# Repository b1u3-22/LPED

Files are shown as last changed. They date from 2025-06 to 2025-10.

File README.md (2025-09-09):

# LPED

Highly customizable Low-power Electronic Playing Dice

> This project started as a bachelors thesis, the original repository can be found [here](https://git.fit.vutbr.cz/xsedla2e/BP-LPED)

## Features

* Separate charging station for charging the dice via pogo-pins
* Changing the dice shape with custom sleeves 
* The dice can be configured to support any shape with up to 60 sides
* Up to 10 profiles can be saved onboard 

### Hardware 

* The dice uses a nRF52833 microcontroller with FXLS8974CF accelerometer
* Instead of battery it uses hybrid super-capacitor with 20 F capacity that provides up to 8 hours of game time with charging time of 15 minutes
* RGB LED on-board the dice
* The charger has separate battery providing up to two full dice charges
* The 3D models of the charging dock have been optimized for 3D printing and they do not require any supports
	* However, one heat inserts and 4 magnets (6x6x2mm) are necessary for the assembly

### Firmware 

* The dice transmits the landed numbers via BLE broadcast advertisement
	* To ensure they get to the client application, they are sent multiple times with unique identifier
* For configuration it is necessary to connect to the dice
	* It provides all the necessary parameters via characteristics in custom GATT service
* It saves the whole configuration in the FLASH memory of the dice, making it independent on the used client application
* Each side can have its own physical position on the dice and its own number, making it possible to create dice with custom non-standard shapes

## Project structure 
* `/hardware` - schematics, 3D models and PCB design files for dice, charger and programming adapter
	* The schematics and PCB designs were made in KiCad 
	* The printable models were made in FreeCAD 
* `/firmware` - Zephyr firmware running on the dice

## Versioning info 
* Repository uses `major.minor` format
	* `major` is incremented with each major hardware revision or significant firmware update that causes the implementation to be incompatible with previous version
	* `minor` is used for firmware fixes and patches that don't affect backwards compatibility
	* Branch names are created based on major revisions 
* PCBs have their own version code on them that follows standard `major.minor` format
	* `major` is used for drastic changes to the boards, such as MCU swap or change of pinout
	* `minor` is used for hardware fixes and patches

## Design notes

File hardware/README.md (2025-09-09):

# Hardware designs 
* Schematic, PCB design files and used 3D models used in the design for the die, charging dock and programming adapter
* The `complete_bom.csv` contains BOM with components selected from Mouser

## Structure
1. `lped`
    * Design files for the die
2. `lped_dock`
    * Design files for for the modular charging station and single dice charging station
3. `lped_prog`
    * Design files for the programming adapter
2. `3d_models`
    * 3D models used in PCB design files in all three boards

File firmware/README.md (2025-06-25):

# Firmware for LPED
* Zephyr firmware running on the die
* The `src/lib` contains helper function and structure definitions for controlling the die, dock and determining the current number on top
* A FXLS8974 driver is required to be placed in `modules` and it is available at: https://git.fit.vutbr.cz/xsedla2e/BP-FXLS89xx-Driver

## `src/lib` structure
1. `bma400`
    * Older driver for BMA400 accelerometer
    * Not currently used
2. `bt`
    * Contains structure for Bluetooth aspects of the die and functions to send messages and change the Bluetooth states
    * `bt_dice.h` also contains definitions for message types
3. `dock`
    * Contains structure and functions for controlling the charging dock - LED and button handling
4. `phy`
    * Contains structure for physical aspects of the die - controlling the LED and getting the capacitor state
5. `side`
    * Contains array with all supported sides and their vector values and function to determine the current side
6. `led_defs.h`
    * LED speed definitions

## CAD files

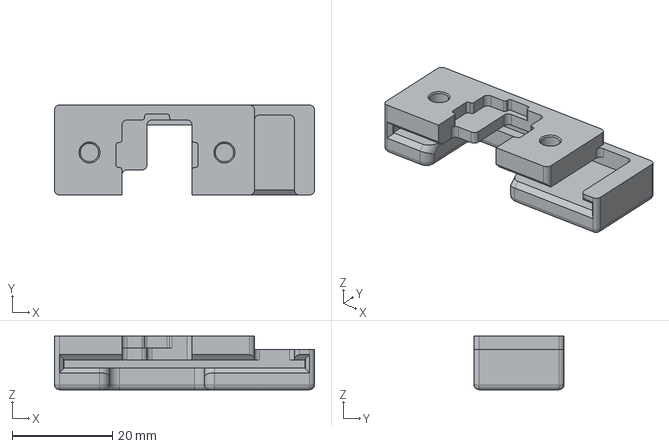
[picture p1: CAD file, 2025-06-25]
hardware/lped_prog/3d_models/step/main_body.step
52.0 x 18.0 x 10.7 mm

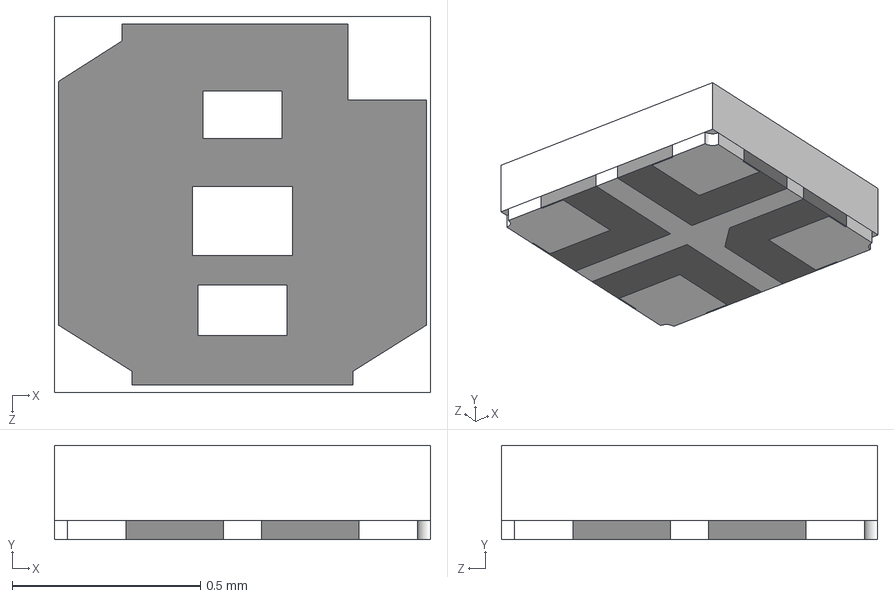
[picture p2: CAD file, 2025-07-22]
hardware/3d_models/LTRBR37G-4R4S-0125-0.stp
1.00 x 0.25 x 1.00 mm

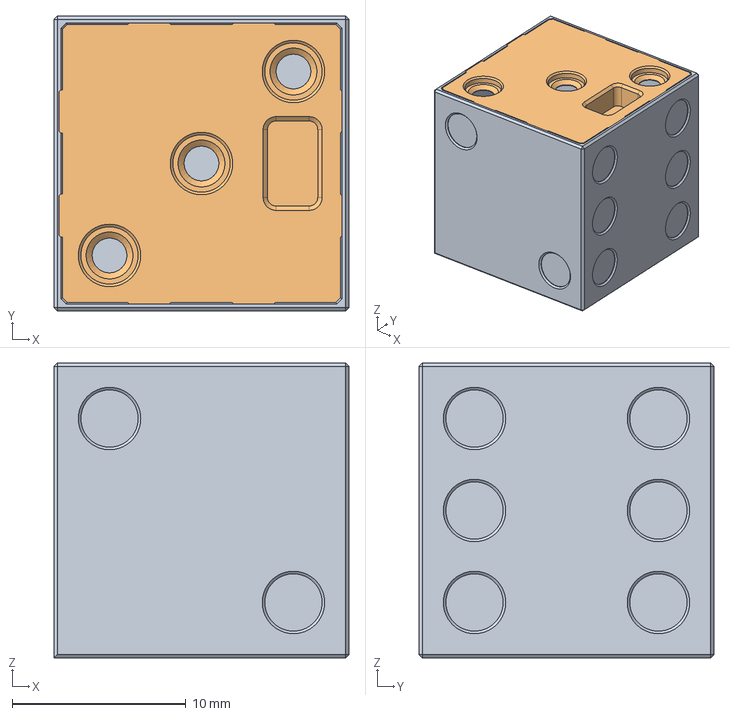
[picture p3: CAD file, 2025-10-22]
hardware/lped/3d_models/die_6.FCStd
17.0 x 17.0 x 17.0 mm
cap

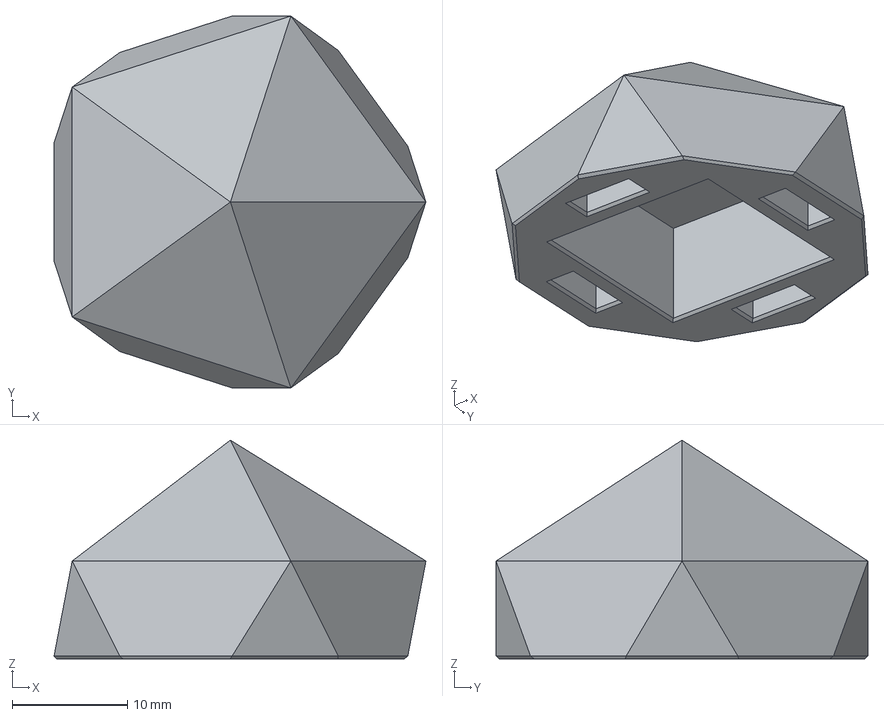
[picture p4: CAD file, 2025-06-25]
hardware/lped/3d_models/step/dice_20_top.step
32.3 x 32.3 x 19.0 mm

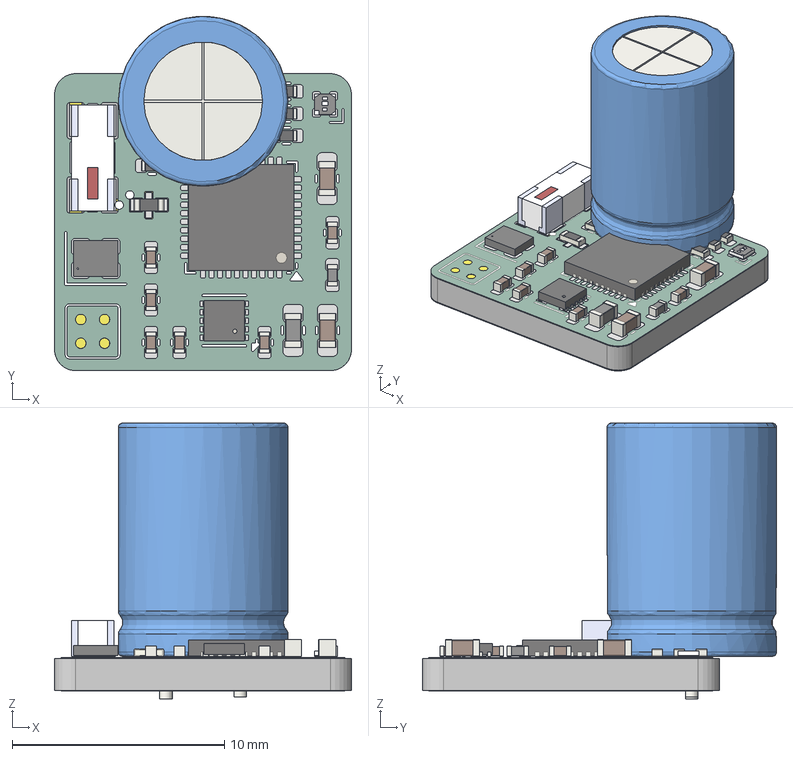
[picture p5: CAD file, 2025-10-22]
hardware/lped/schematics/3d_models/lped_pcb.step
14.0 x 16.7 x 13.0 mm
fxls8974cf
C_0603_1608Metric x 2
C_Radial_D8.0mm_H11.5mm_P3.50mm
LTRBR37G-4R4S-0125-0
R_0402_1005Metric x 5
C_0402_1005Metric x 6
QFN-40-1EP_5x5mm_P0.4mm_EP3.6x3.6mm
L_0402_1005Metric
L_0603_1608Metric
FA-128_EPS
2450AT42E010BE
lped_copper
lped_pad
lped_via
lped_silkscreen x 2
lped_soldermask x 2
lped_PCB

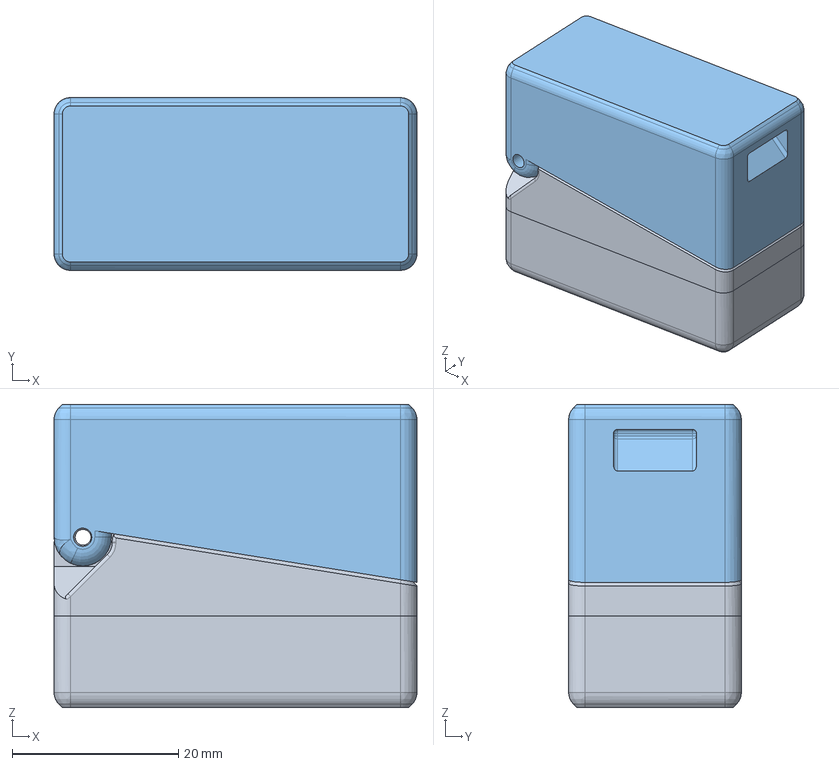
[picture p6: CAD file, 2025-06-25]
hardware/lped_dock/single_dock/3d_models/single_charger.FCStd
43.7 x 20.8 x 36.5 mm
bottom
R_0402_1005Metric
USB_C_Receptacle_GCT_USB4105-xx-A_16P_TopMnt_Horizontal
USB_C_Receptacle_GCT_USB4105-xx-A_16P_TopMnt_Horizontal001
USB_C_Receptacle_GCT_USB4105-xx-A_16P_TopMnt_Horizontal002
USB_C_Receptacle_GCT_USB4105-xx-A_16P_TopMnt_Horizontal003
USB_C_Receptacle_GCT_USB4105-xx-A_16P_TopMnt_Horizontal004
USB_C_Receptacle_GCT_USB4105-xx-A_16P_TopMnt_Horizontal005
USB_C_Receptacle_GCT_USB4105-xx-A_16P_TopMnt_Horizontal006
USB_C_Receptacle_GCT_USB4105-xx-A_16P_TopMnt_Horizontal007
USB_C_Receptacle_GCT_USB4105-xx-A_16P_TopMnt_Horizontal008
USB_C_Receptacle_GCT_USB4105-xx-A_16P_TopMnt_Horizontal009
USB_C_Receptacle_GCT_USB4105-xx-A_16P_TopMnt_Horizontal010
USB_C_Receptacle_GCT_USB4105-xx-A_16P_TopMnt_Horizontal011
USB_C_Receptacle_GCT_USB4105-xx-A_16P_TopMnt_Horizontal012
USB_C_Receptacle_GCT_USB4105-xx-A_16P_TopMnt_Horizontal013
USB_C_Receptacle_GCT_USB4105-xx-A_16P_TopMnt_Horizontal014
USB_C_Receptacle_GCT_USB4105-xx-A_16P_TopMnt_Horizontal015
USB_C_Receptacle_GCT_USB4105-xx-A_16P_TopMnt_Horizontal016
USB_C_Receptacle_GCT_USB4105-xx-A_16P_TopMnt_Horizontal017
USB_C_Receptacle_GCT_USB4105-xx-A_16P_TopMnt_Horizontal018
USB_C_Receptacle_GCT_USB4105-xx-A_16P_TopMnt_Horizontal019
USB_C_Receptacle_GCT_USB4105-xx-A_16P_TopMnt_Horizontal020
USB_C_Receptacle_GCT_USB4105-xx-A_16P_TopMnt_Horizontal021
USB_C_Receptacle_GCT_USB4105-xx-A_16P_TopMnt_Horizontal022
USB_C_Receptacle_GCT_USB4105-xx-A_16P_TopMnt_Horizontal023
USB_C_Receptacle_GCT_USB4105-xx-A_16P_TopMnt_Horizontal024
USB_C_Receptacle_GCT_USB4105-xx-A_16P_TopMnt_Horizontal025
USB_C_Receptacle_GCT_USB4105-xx-A_16P_TopMnt_Horizontal026
USB_C_Receptacle_GCT_USB4105-xx-A_16P_TopMnt_Horizontal027
USB_C_Receptacle_GCT_USB4105-xx-A_16P_TopMnt_Horizontal028
USB_C_Receptacle_GCT_USB4105-xx-A_16P_TopMnt_Horizontal029
USB_C_Receptacle_GCT_USB4105-xx-A_16P_TopMnt_Horizontal030
USB_C_Receptacle_GCT_USB4105-xx-A_16P_TopMnt_Horizontal031
USB_C_Receptacle_GCT_USB4105-xx-A_16P_TopMnt_Horizontal032
USB_C_Receptacle_GCT_USB4105-xx-A_16P_TopMnt_Horizontal033
USB_C_Receptacle_GCT_USB4105-xx-A_16P_TopMnt_Horizontal034
USB_C_Receptacle_GCT_USB4105-xx-A_16P_TopMnt_Horizontal035
R_0402_1005Metric001
L_0805_2012Metric
pogo_pin-7mm
C_0603_1608Metric
APTD2012LSURCK
APTD2012LSURCK001
APTD2012LSURCK002
APTD2012LSURCK003
APTD2012LSURCK004
APTD2012LSURCK005
C_0603_1608Metric001
R_0402_1005Metric002
R_0402_1005Metric003
pogo_pin-7mm001
R_0402_1005Metric004
R_2512_6332Metric
pogo_pin-7mm002
SW_SPST_PTS645
pogo_pin-7mm003
pogo_pin-7mm004
R_0402_1005Metric005
R_0402_1005Metric006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

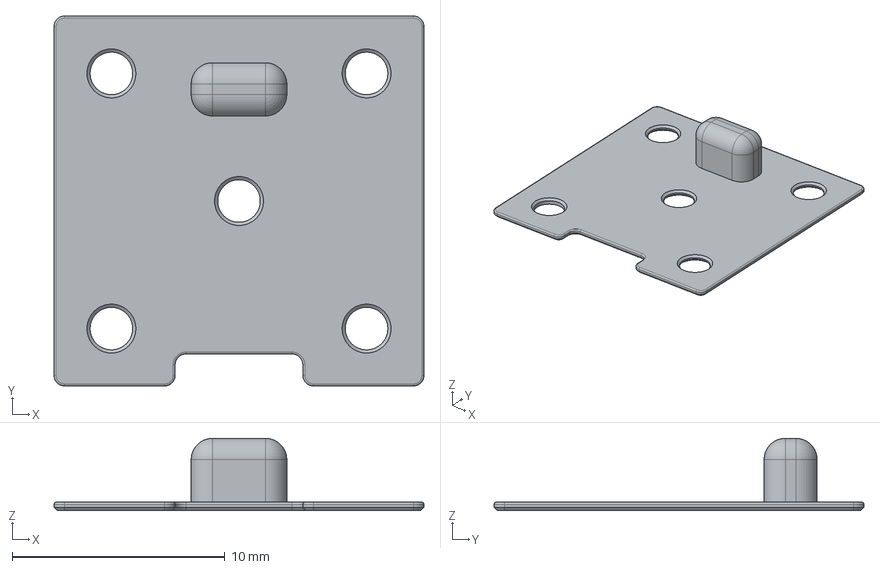
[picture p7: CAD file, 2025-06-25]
hardware/lped_dock/single_dock/3d_models/step/bay_insert.step
17.4 x 17.4 x 3.40 mm

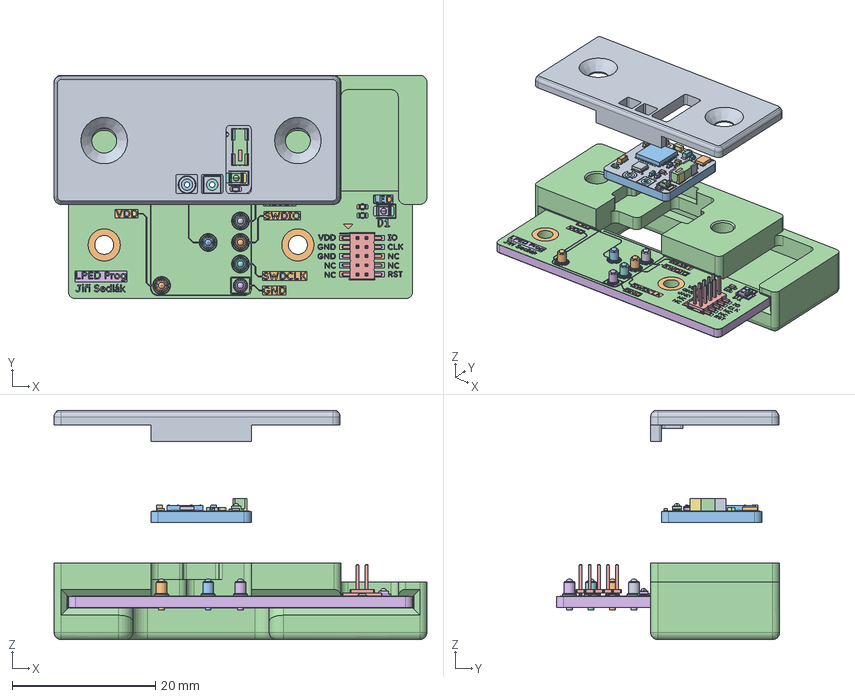
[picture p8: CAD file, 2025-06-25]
hardware/lped_prog/3d_models/hard_clamp_top.FCStd
52.0 x 31.2 x 32.0 mm
clamp
pogo_pin-3mm
pogo_pin-3mm001
R_0402_1005Metric
PinHeader_2x05_P1.27mm_Vertical_SMD
pogo_pin-3mm002
R_0402_1005Metric001
pogo_pin-3mm003
pogo_pin-3mm004
pogo_pin-3mm005
APTD2012LSURCK
APTD2012LSURCK001
APTD2012LSURCK002
APTD2012LSURCK003
APTD2012LSURCK004
APTD2012LSURCK005
lped_prog_copper
lped_prog_copper001
lped_prog_copper002
lped_prog_copper003
lped_prog_copper004
lped_prog_copper005
lped_prog_copper006
lped_prog_copper007
lped_prog_copper008
lped_prog_pad
lped_prog_pad001
lped_prog_pad002
lped_prog_pad003
lped_prog_pad004
lped_prog_pad005
lped_prog_pad006
lped_prog_pad007
lped_prog_pad008
lped_prog_pad009
lped_prog_pad010
lped_prog_pad011
lped_prog_pad012
lped_prog_pad013
lped_prog_pad014
lped_prog_pad015
lped_prog_pad016
lped_prog_pad017
lped_prog_pad018
lped_prog_pad019
lped_prog_pad020
lped_prog_pad021
lped_prog_pad022
lped_prog_pad023
lped_prog_pad024
lped_prog_pad025
lped_prog_pad026
lped_prog_pad027
lped_prog_pad028
lped_prog_pad029
lped_prog_pad030
lped_prog_pad031
lped_prog_pad032
lped_prog_pad033
lped_prog_pad034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

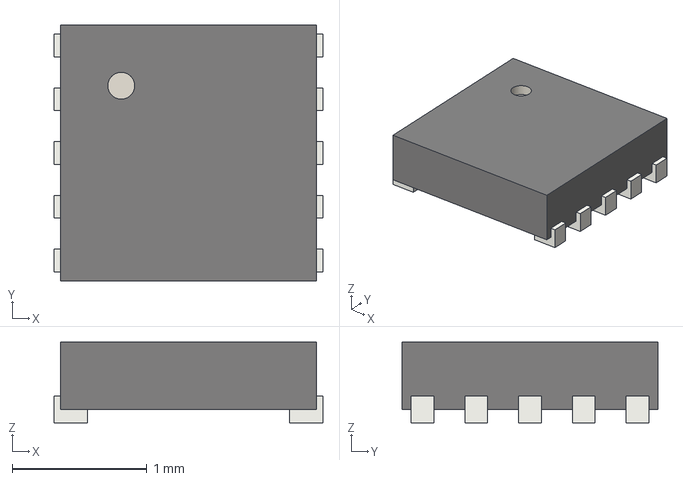
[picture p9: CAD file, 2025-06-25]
hardware/3d_models/fxls8974cf.step
2.00 x 1.90 x 0.6 mm

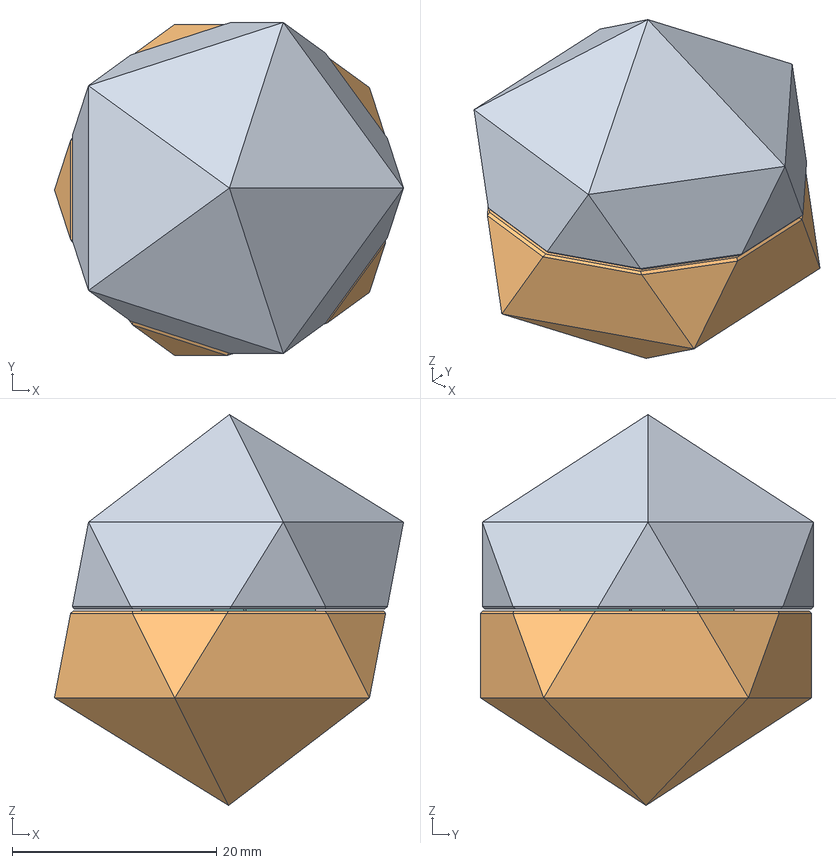
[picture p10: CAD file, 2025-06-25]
hardware/lped/3d_models/die_20.FCStd
34.1 x 32.5 x 38.1 mm
top
bottom
insert
C_0402_1005Metric
C_Radial_D8.0mm_H11.5mm_P3.50mm
C_0402_1005Metric001
fxls8974cf
C_0603_1608Metric
C_0402_1005Metric002
R_0402_1005Metric
R_0402_1005Metric001
C_0402_1005Metric003
C_0402_1005Metric004
C_0603_1608Metric001
APTD2012LSURCK
APTD2012LSURCK001
APTD2012LSURCK002
APTD2012LSURCK003
APTD2012LSURCK004
APTD2012LSURCK005
C_0603_1608Metric002
C_0402_1005Metric005
FA-128_EPS
FA-128_EPS001
FA-128_EPS002
FA-128_EPS003
FA-128_EPS004
FA-128_EPS005
L_0402_1005Metric
C_0402_1005Metric006
R_0402_1005Metric002
L_0603_1608Metric
QFN-32-1EP_5x5mm_P0.5mm_EP3.45x3.45mm
2450AT42E010BE
2450AT42E010BE001
2450AT42E010BE002
2450AT42E010BE003
2450AT42E010BE004
2450AT42E010BE005
L_0402_1005Metric001
lped_copper
lped_copper001
lped_copper002
lped_copper003
lped_copper004
lped_copper005
lped_copper006
lped_copper007
lped_copper008
lped_copper009
lped_copper010
lped_copper011
lped_copper012
lped_copper013
lped_copper014
lped_copper015
lped_copper016
lped_copper017
lped_copper018
lped_copper019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

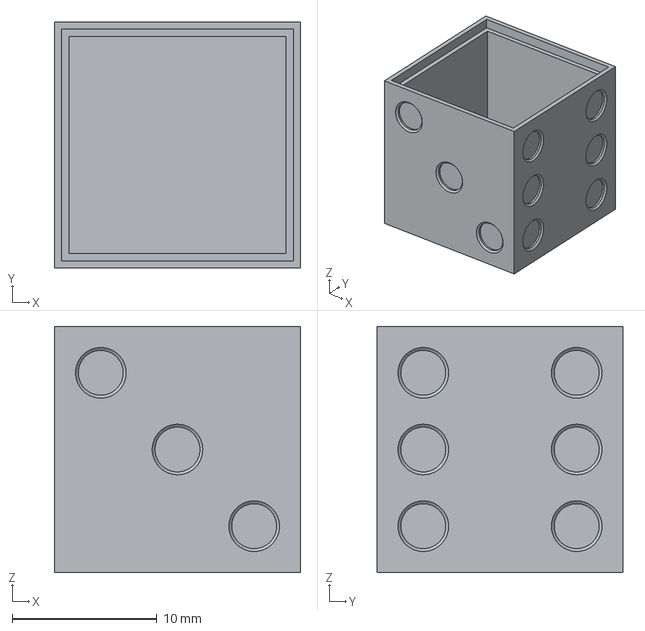
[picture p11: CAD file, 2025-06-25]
hardware/lped/3d_models/step/body.step
17.0 x 17.0 x 17.0 mm

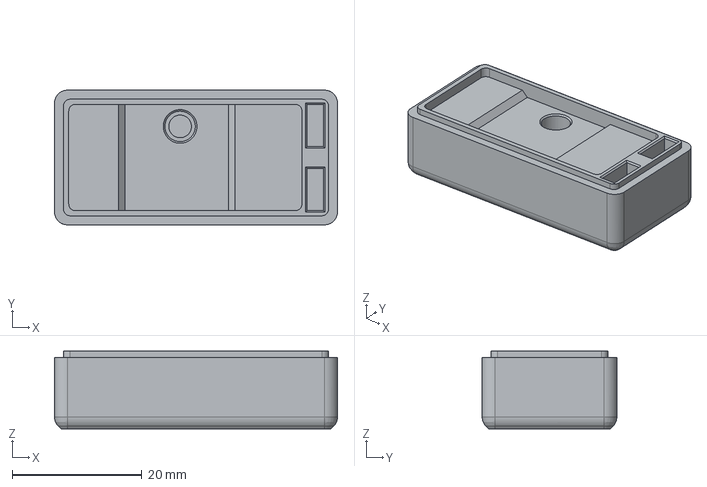
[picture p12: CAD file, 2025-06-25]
hardware/lped_dock/single_dock/3d_models/step/bottom_body.step
43.7 x 20.8 x 12.0 mm

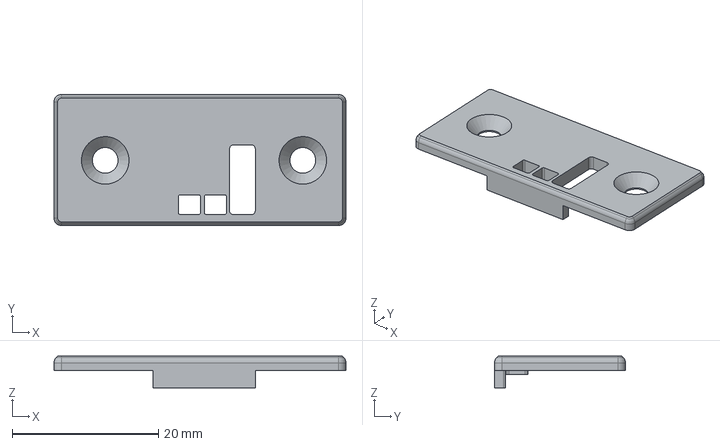
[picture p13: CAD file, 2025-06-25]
hardware/lped_prog/3d_models/step/clamp.step
39.9 x 17.9 x 4.35 mm

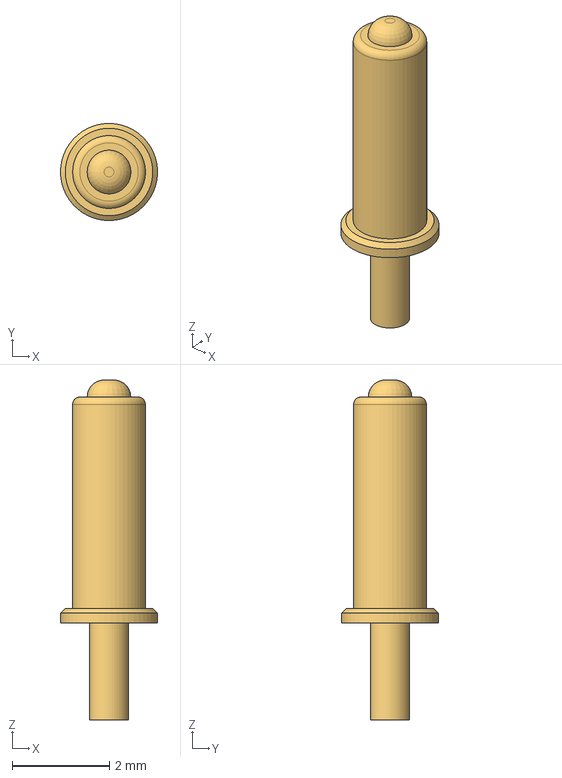
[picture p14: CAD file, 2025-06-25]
hardware/3d_models/pogo_pin-7mm.step
2.00 x 2.00 x 7.00 mm

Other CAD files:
hardware/lped/3d_models/step/dice_20_bottom.step
hardware/lped_dock/single_dock/3d_models/step/lped_dock_pcb.step
hardware/lped/3d_models/step/die_20_insert.step
hardware/lped_dock/single_dock/3d_models/step/top_body.step
hardware/3d_models/2450AT42E010BE.step
hardware/3d_models/APTD2012LSURCK.stp
hardware/3d_models/FA-128_EPS.step
hardware/3d_models/nRF52810-QCAA-R.stp
hardware/3d_models/pogo_pin-3mm.step
hardware/3d_models/pogo_pin-7mm.stl
hardware/lped/3d_models/step/cap.step
hardware/lped/3d_models/step/lped_pcb.step
hardware/lped_dock/single_dock/3d_models/step/lid.step
hardware/lped_prog/3d_models/main_body.FCStd

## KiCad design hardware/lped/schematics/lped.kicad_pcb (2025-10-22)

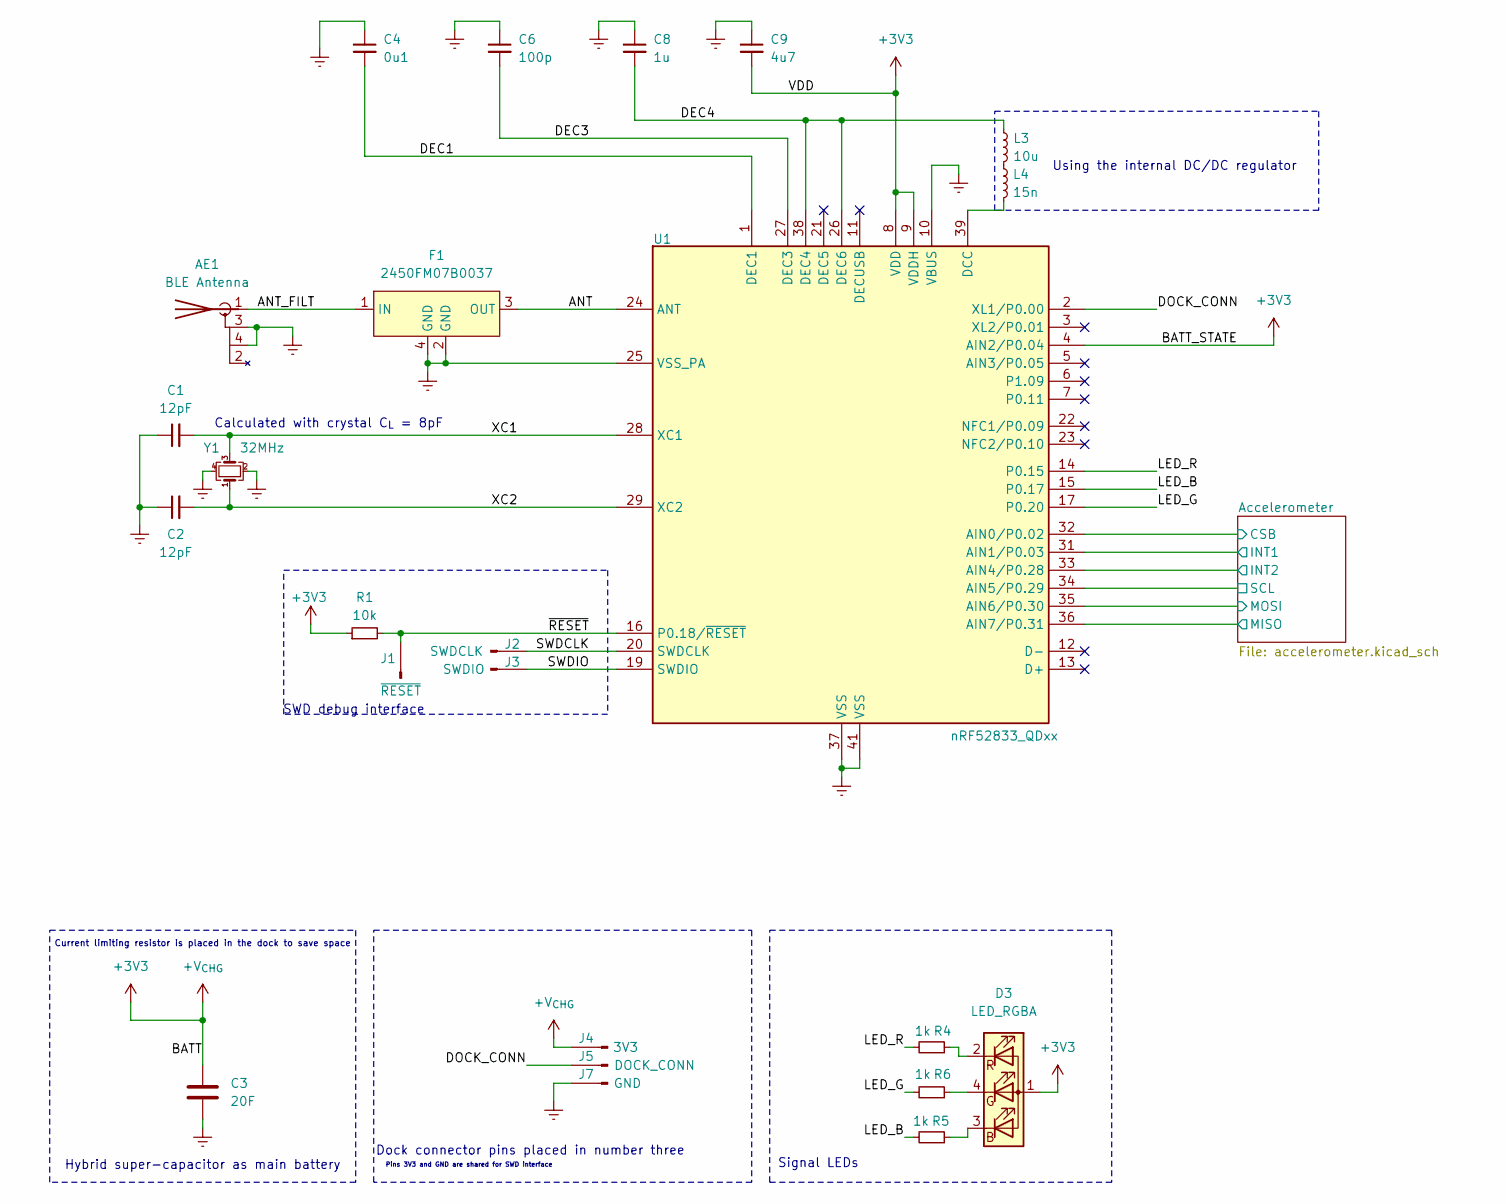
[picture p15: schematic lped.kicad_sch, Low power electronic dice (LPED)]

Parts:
AE1: BLE Antenna; XDCR_2450AT42E010BE
C1, C2: 12pF; C_0402_1005Metric
C3: 20F; C_Radial_D8.0mm_H11.5mm_P3.50mm
C4: 0u1; C_0402_1005Metric
C6: 100p; C_0402_1005Metric
C8: 1u; C_0603_1608Metric
C9: 4u7; C_0603_1608Metric
D3: LED_RGBA; LED_Wurth_150044M155260
F1: 2450FM07B0037; FIL_2450FM07D0034T
J1: ~{RESET}; TestPoint_Pad_D2.0mm
J2: SWDCLK; TestPoint_Pad_D2.0mm
J3: SWDIO; TestPoint_Pad_D2.0mm
J4: 3V3; TestPoint_Pad_D2.0mm
J5: DOCK_CONN; TestPoint_Pad_D2.0mm
J7: GND; TestPoint_Pad_2.0x2.0mm
L3: 10u; L_0603_1608Metric
L4: 15n; L_0402_1005Metric
R1: 10k; R_0402_1005Metric
R4, R5, R6: 1k; R_0402_1005Metric
U1: nRF52833_QDxx; QFN-40-1EP_5x5mm_P0.4mm_EP3.6x3.6mm
Y1: 32MHz; Crystal_SMD_2016-4Pin_2.0x1.6mm

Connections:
+3V3: C3.1, C9.2, D3.1 (A), J4.1, R1.1, U1.4 (AIN2/P0.04), U1.8 (VDD), U1.9 (VDDH), U1.18 (VDD), U1.30 (VDD), U1.40 (VDD); also elsewhere on the board
/ANT: F1.3 (OUT), U1.24 (ANT)
/ANT_FILT: AE1.1 (A), F1.1 (IN)
/Accelerometer/CSB: U1.32 (AIN0/P0.02); also elsewhere on the board
/Accelerometer/INT1: U1.31 (AIN1/P0.03); also elsewhere on the board
/Accelerometer/INT2: U1.33 (AIN4/P0.28); also elsewhere on the board
/Accelerometer/MISO: U1.36 (AIN7/P0.31); also elsewhere on the board
/Accelerometer/MOSI: U1.35 (AIN6/P0.30); also elsewhere on the board
/Accelerometer/SCL: U1.34 (AIN5/P0.29); also elsewhere on the board
/DEC1: C4.2, U1.1 (DEC1)
/DEC3: C6.2, U1.27 (DEC3)
/DEC4: C8.2, L3.1, U1.26 (DEC6), U1.38 (DEC4)
/DOCK_CONN: J5.1, U1.2 (XL1/P0.00)
/LED_B: R5.2, U1.15 (P0.17)
/LED_G: R6.2, U1.17 (P0.20)
/LED_R: R4.2, U1.14 (P0.15)
/SWDCLK: J2.1, U1.20 (SWDCLK)
/SWDIO: J3.1, U1.19 (SWDIO)
/XC1: C1.2, U1.28 (XC1), Y1.3
/XC2: C2.2, U1.29 (XC2), Y1.1
/~RESET: J1.1, R1.2, U1.16 (P0.18/~RESET)
Earth: AE1.3 (Shield), AE1.4 (Shield), C1.1, C2.1, C3.2, C4.1, C6.1, C8.1, C9.1, F1.2 (GND), F1.4 (GND), J7.1, U1.10 (VBUS), U1.25 (VSS_PA), U1.37 (VSS), U1.41 (VSS), Y1.2, Y1.4; also elsewhere on the board
unnamed: D3.3 (BK), R5.1
unnamed: D3.4 (GK), R6.1
unnamed: D3.2 (RK), R4.1
unnamed: L3.2, L4.1
unnamed: L4.2, U1.39 (DCC)

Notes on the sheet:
Calculated with crystal C_{L} = 8pF
SWD debug interface
Current limiting resistor is placed in the dock to save space
Signal LEDs
Dock connector pins placed in number three
Hybrid super-capacitor as main battery
Using the internal DC/DC regulator
Pins 3V3 and GND are shared for SWD interface

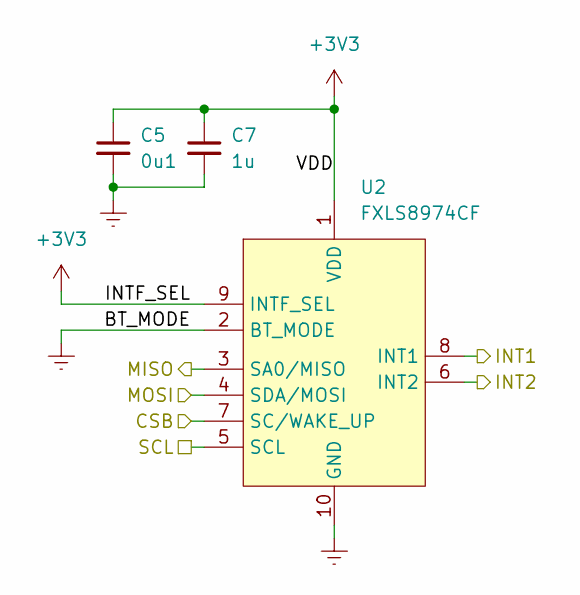
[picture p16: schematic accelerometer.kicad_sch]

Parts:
C5: 0u1; C_0402_1005Metric
C7: 1u; C_0402_1005Metric
U2: FXLS8974CF; DFN-10_2x2mm_P0.4mm

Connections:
+3V3: C5.1, C7.1, U2.1 (VDD), U2.9 (INTF_SEL); also elsewhere on the board
/Accelerometer/CSB: U2.7 (SC/WAKE_UP); also elsewhere on the board
/Accelerometer/INT1: U2.8 (INT1); also elsewhere on the board
/Accelerometer/INT2: U2.6 (INT2); also elsewhere on the board
/Accelerometer/MISO: U2.3 (SA0/MISO); also elsewhere on the board
/Accelerometer/MOSI: U2.4 (SDA/MOSI); also elsewhere on the board
/Accelerometer/SCL: U2.5 (SCL); also elsewhere on the board
Earth: C5.2, C7.2, U2.2 (BT_MODE), U2.10 (GND); also elsewhere on the board

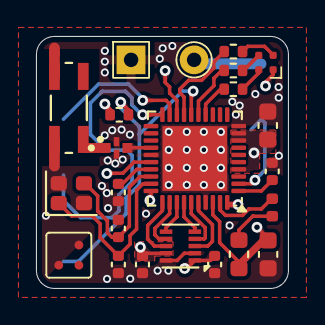
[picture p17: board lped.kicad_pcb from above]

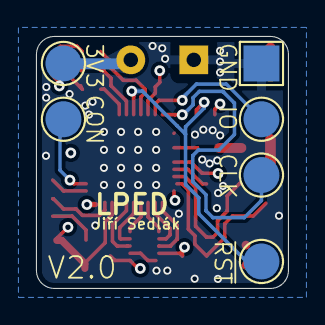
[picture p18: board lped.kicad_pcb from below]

Board: 4 copper layers, 14.0 x 14.0 mm, 27 parts (6 on the bottom side), 27 nets.

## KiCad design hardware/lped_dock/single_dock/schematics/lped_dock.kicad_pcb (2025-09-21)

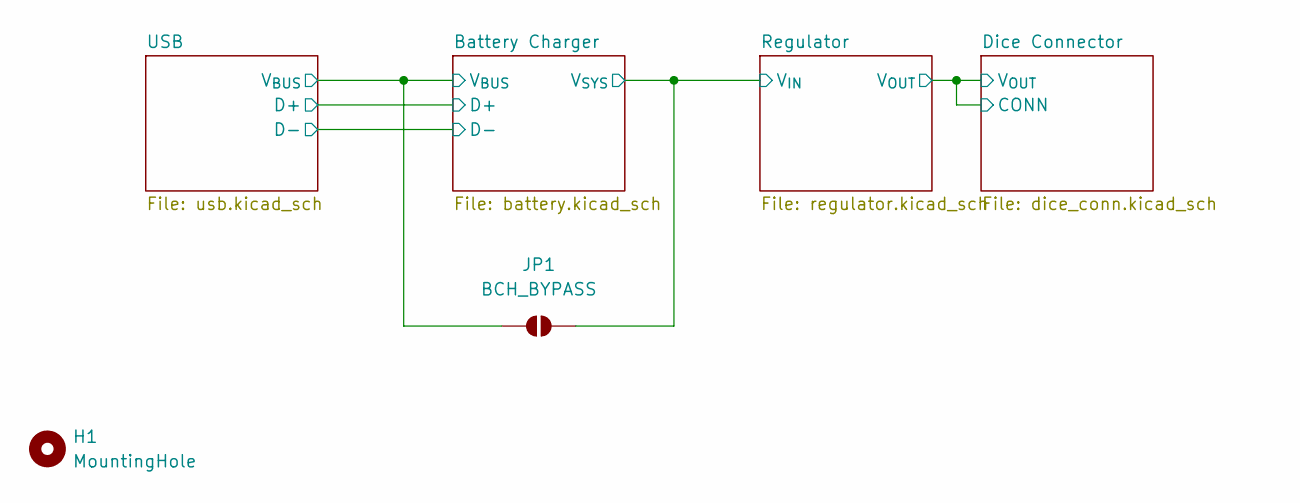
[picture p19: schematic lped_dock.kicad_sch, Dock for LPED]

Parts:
H1: MountingHole; MountingHole_3.2mm_M3
JP1: BCH_BYPASS; SolderJumper-2_P1.3mm_Open_Pad1.0x1.5mm

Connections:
/Battery Charger/V_{BUS}: JP1.1 (A); also elsewhere on the board
/Battery Charger/V_{SYS}: JP1.2 (B); also elsewhere on the board

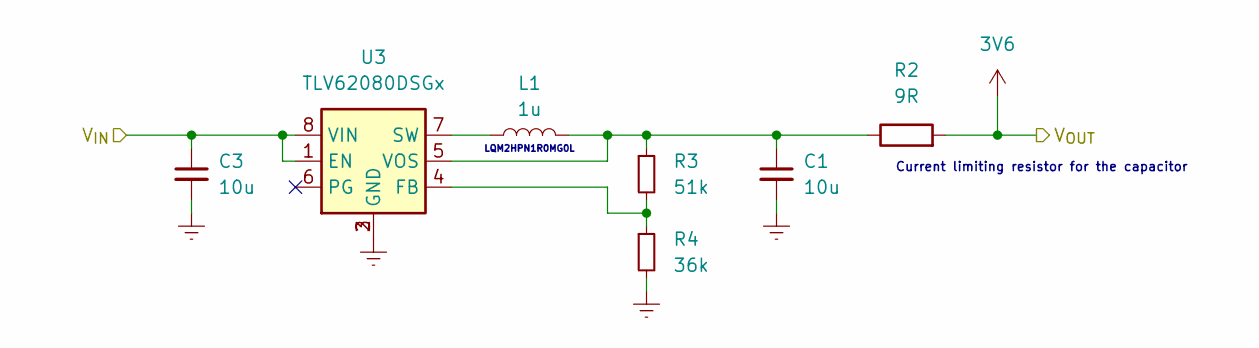
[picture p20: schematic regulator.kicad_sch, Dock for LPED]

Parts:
C1, C3: 10u; C_0603_1608Metric
L1: 1u; L_1008_2520Metric
R2: 9R; R_2512_6332Metric
R3: 51k; R_0402_1005Metric
R4: 36k; R_0402_1005Metric
U3: TLV62080DSGx; WSON-8-1EP_2x2mm_P0.5mm_EP0.9x1.6mm

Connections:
3V6: R2.2; also elsewhere on the board
/Battery Charger/V_{SYS}: C3.1, U3.1 (EN), U3.8 (VIN); also elsewhere on the board
Earth: C1.2, C3.2, R4.2, U3.2 (GND), U3.3 (GND), U3.9 (GND); also elsewhere on the board
unnamed: R3.2, R4.1, U3.4 (FB)
unnamed: L1.1, U3.7 (SW)
unnamed: C1.1, L1.2, R2.1, R3.1, U3.5 (VOS)

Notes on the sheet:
Current limiting resistor for the capacitor
LQM2HPN1R0MG0L

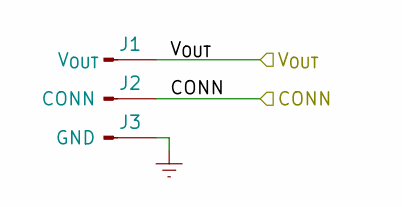
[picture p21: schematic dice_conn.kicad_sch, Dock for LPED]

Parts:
J1: V_{OUT}; Pin_D0.9mm_L10.0mm_W2.4mm_FlatFork
J2: CONN; Pin_D0.9mm_L10.0mm_W2.4mm_FlatFork
J3: GND; Pin_D0.9mm_L10.0mm_W2.4mm_FlatFork

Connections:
3V6: J1.1, J2.1; also elsewhere on the board
Earth: J3.1; also elsewhere on the board

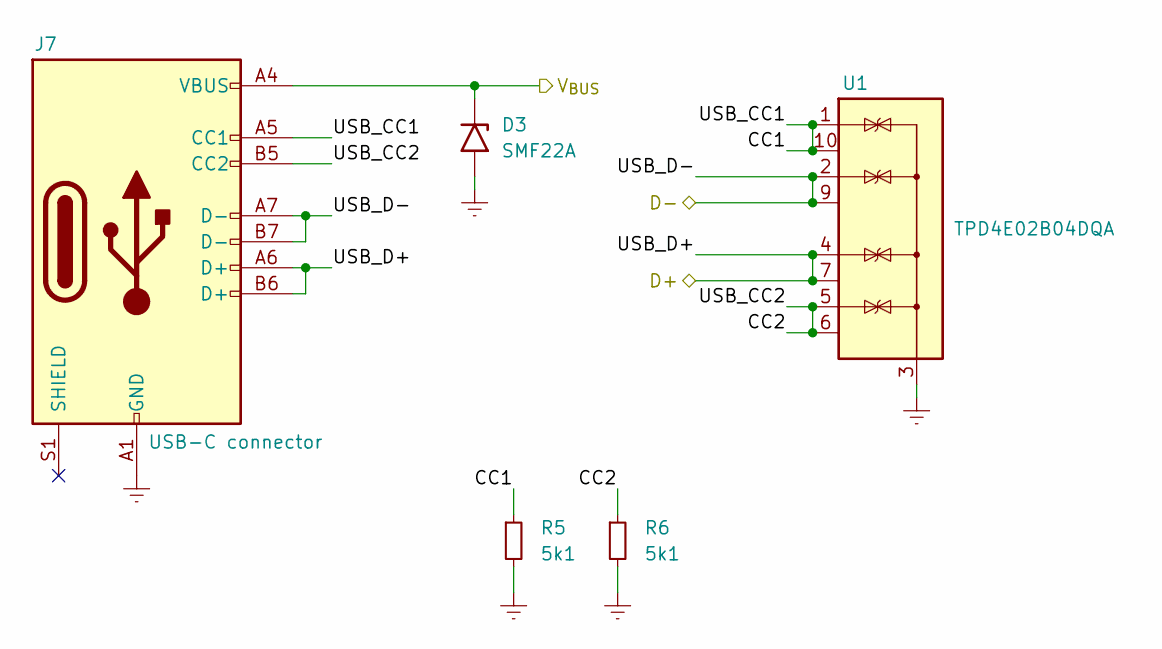
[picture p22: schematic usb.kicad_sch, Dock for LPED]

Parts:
D3: SMF22A; D_SOD-123
J7: USB-C connector; USB_C_Receptacle_GCT_USB4105-xx-A_16P_TopMnt_Horizontal
R5, R6: 5k1; R_0402_1005Metric
U1: TPD4E02B04DQA; USON-10_2.5x1.0mm_P0.5mm

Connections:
/Battery Charger/V_{BUS}: D3.1 (A1), J7.A4 (VBUS), J7.A9 (VBUS), J7.B4 (VBUS), J7.B9 (VBUS); also elsewhere on the board
/USB/CC1: J7.A5 (CC1), R5.1, U1.1 (IO1), U1.10 (NC)
/USB/CC2: J7.B5 (CC2), R6.1, U1.5 (IO4), U1.6 (NC)
/USB/USB_D+: J7.A6 (D+), J7.B6 (D+), U1.4 (IO3), U1.7 (NC); also elsewhere on the board
/USB/USB_D-: J7.A7 (D-), J7.B7 (D-), U1.2 (IO2), U1.9 (NC); also elsewhere on the board
Earth: D3.2 (A2), J7.A1 (GND), J7.A12 (GND), J7.B1 (GND), J7.B12 (GND), R5.2, R6.2, U1.3 (G), U1.8 (G); also elsewhere on the board

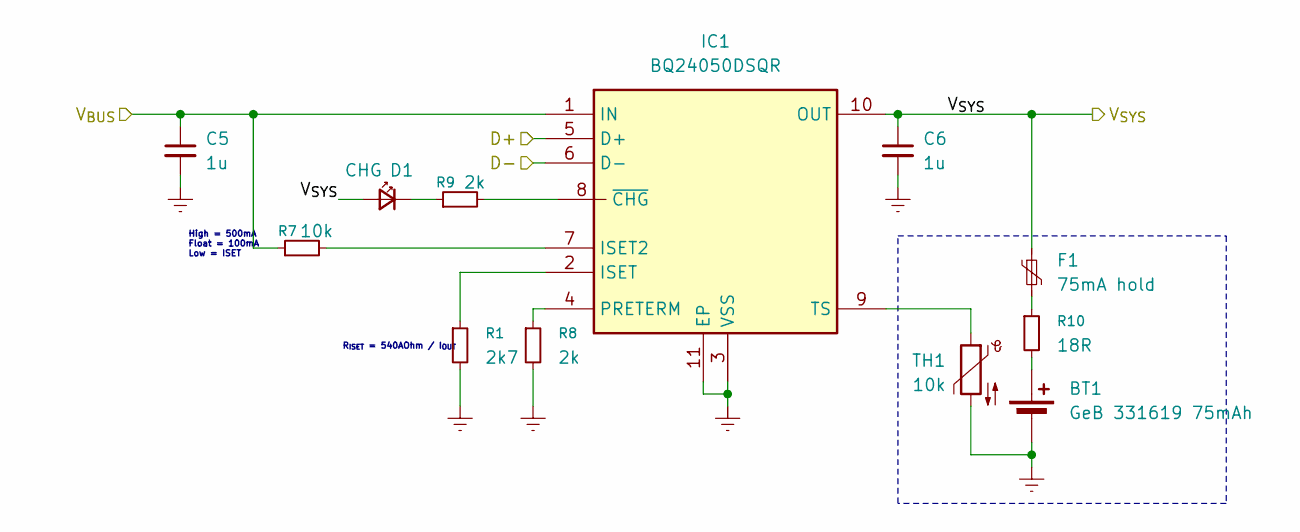
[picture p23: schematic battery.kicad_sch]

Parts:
BT1: GeB 331619 75mAh; JST_PH_S2B-PH-K_1x02_P2.00mm_Horizontal
C5, C6: 1u; C_0603_1608Metric
D1: CHG; LED_0805_2012Metric
F1: 75mA hold; Fuse_1206_3216Metric
IC1: BQ24050DSQR; SON40P200X200X80-11N; Manufacturer_Part_Number BQ24050DSQR; Mouser Part Number 595-BQ24050DSQR
R1: 2k7; R_0402_1005Metric
R7: 10k; R_0402_1005Metric
R8, R9: 2k; R_0402_1005Metric
R10: 18R; R_1206_3216Metric
TH1: 10k; R_0402_1005Metric

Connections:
/Battery Charger/V_{BUS}: C5.1, IC1.1 (IN), R7.1; also elsewhere on the board
/Battery Charger/V_{SYS}: C6.1, D1.2 (A), F1.1, IC1.10 (OUT); also elsewhere on the board
/USB/USB_D+: IC1.5 (D+); also elsewhere on the board
/USB/USB_D-: IC1.6 (D-); also elsewhere on the board
Earth: BT1.2 (-), C5.2, C6.2, IC1.3 (VSS), IC1.11 (EP), R1.2, R8.2, TH1.2; also elsewhere on the board
unnamed: BT1.1 (+), R10.2
unnamed: D1.1 (K), R9.1
unnamed: F1.2, R10.1
unnamed: IC1.7 (ISET2), R7.2
unnamed: IC1.2 (ISET), R1.1
unnamed: IC1.4 (PRETERM), R8.1
unnamed: IC1.9 (TS), TH1.1
unnamed: IC1.8 (~CHG), R9.2

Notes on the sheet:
High = 500mA Float = 100mA Low = ISET
R_{ISET} = 540AOhm / I_{OUT}

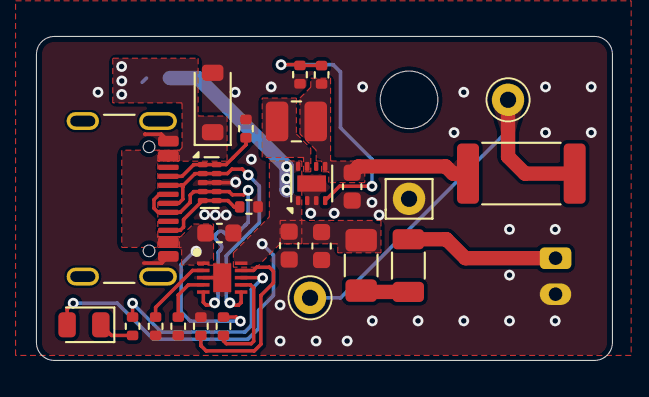
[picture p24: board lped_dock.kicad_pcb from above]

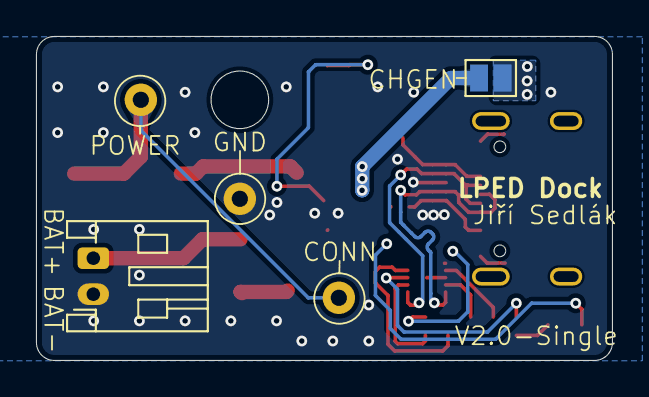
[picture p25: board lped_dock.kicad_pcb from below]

Board: 2 copper layers, 32.0 x 18.0 mm, 29 parts (2 on the bottom side), 19 nets.

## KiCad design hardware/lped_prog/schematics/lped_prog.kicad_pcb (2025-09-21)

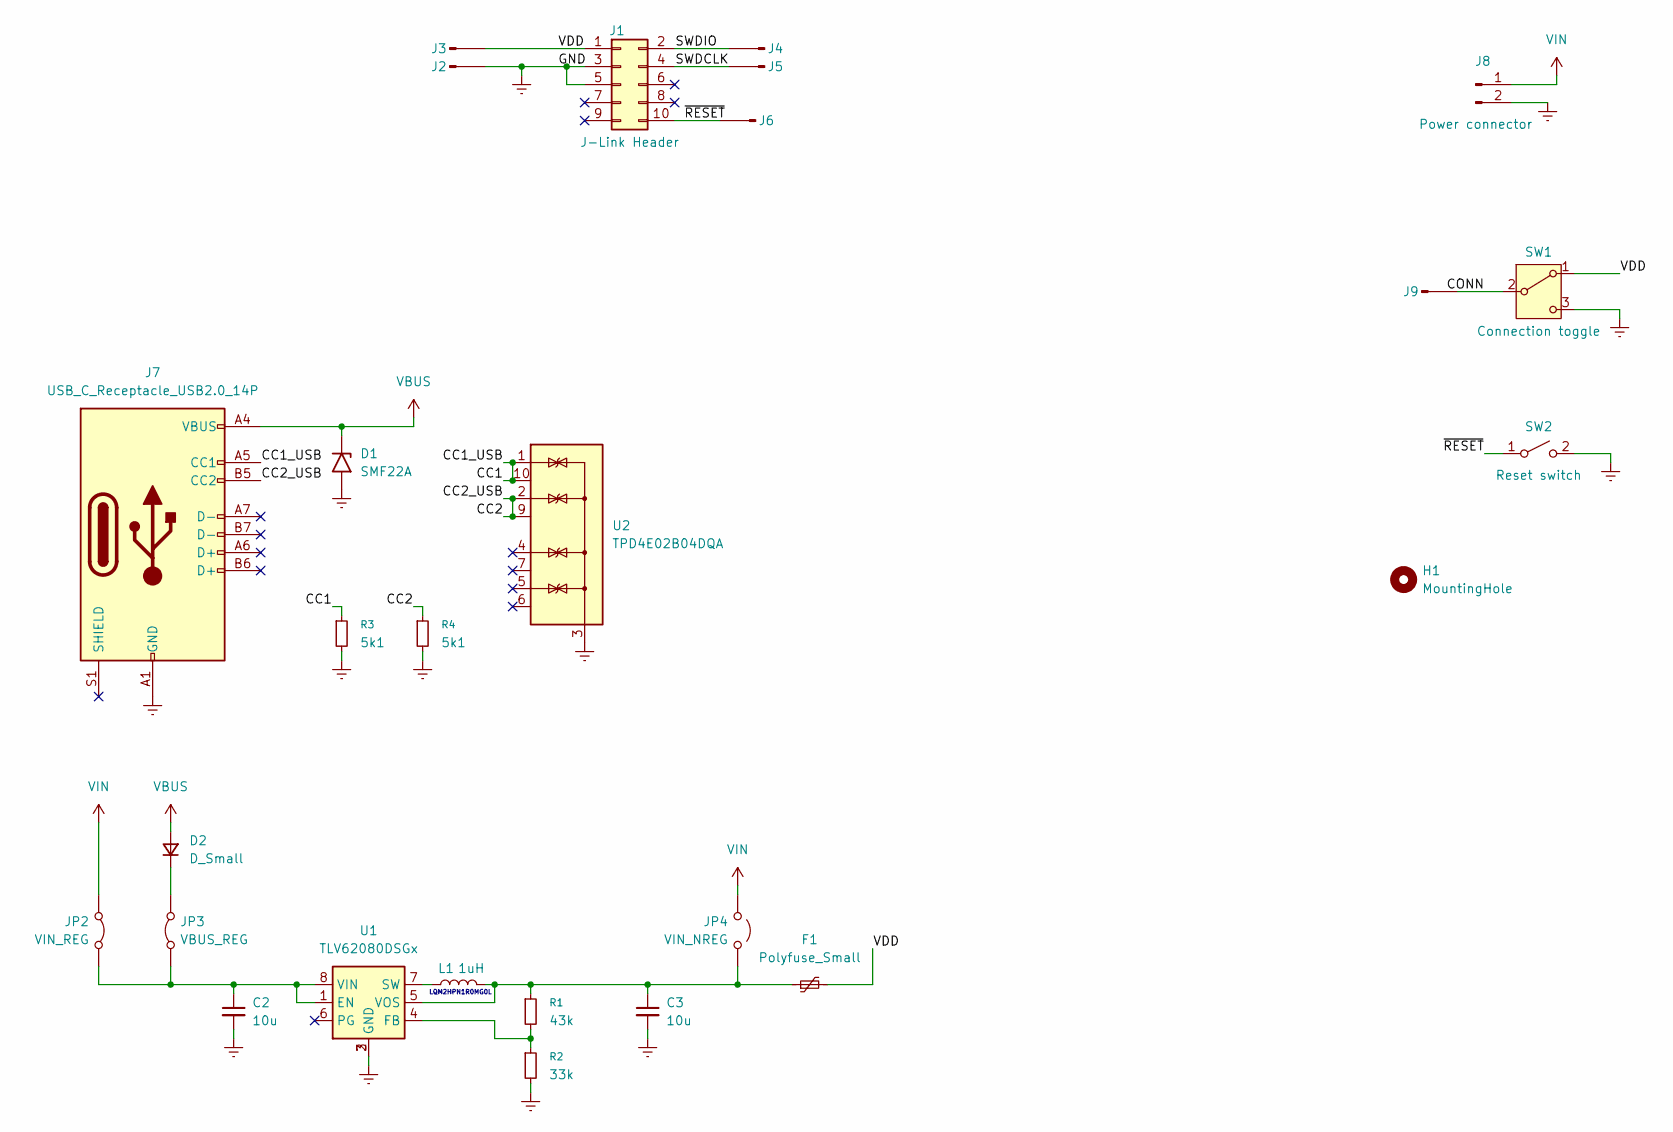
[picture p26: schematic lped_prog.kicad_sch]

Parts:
C2, C3: 10u; C_0603_1608Metric
D1: SMF22A; D_SMF
D2: D_Small; D_SOD-123F
F1: Polyfuse_Small; Fuse_1206_3216Metric
H1: MountingHole; MountingHole_3.2mm_M3
J1: J-Link Header; PinHeader_2x05_P1.27mm_Vertical_SMD
J2, J3, J4, J5, J6, J9: Conn_01x01_Pin; Pin_D0.9mm_L10.0mm_W2.4mm_FlatFork
J7: USB_C_Receptacle_USB2.0_14P; USB_C_Receptacle_GCT_USB4105-xx-A_16P_TopMnt_Horizontal
J8: Power connector; PinHeader_1x02_P2.54mm_Vertical
JP2: VIN_REG; PinHeader_1x02_P2.54mm_Vertical
JP3: VBUS_REG; PinHeader_1x02_P2.54mm_Vertical
JP4: VIN_NREG; PinHeader_1x02_P2.54mm_Vertical
L1: 1uH; L_1008_2520Metric
R1: 43k; R_0402_1005Metric
R2: 33k; R_0402_1005Metric
R3, R4: 5k1; R_0402_1005Metric
SW1: Connection toggle; EG1215AA
SW2: Reset switch; SW_PUSH_6mm_H4.3mm
U1: TLV62080DSGx; WSON-8-1EP_2x2mm_P0.5mm_EP0.9x1.6mm
U2: TPD4E02B04DQA; USON-10_2.5x1.0mm_P0.5mm

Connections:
/CC1: J7.A5 (CC1), R3.1, U2.1 (IO1), U2.10 (NC)
/CC2: J7.B5 (CC2), R4.1, U2.2 (IO2), U2.9 (NC)
/CONN: J9.1, SW1.2 (B)
/SWDCLK: J1.4, J5.1
/SWDIO: J1.2, J4.1
/VDD: F1.2, J1.1, J3.1, SW1.1 (A)
/~RESET: J1.10, J6.1, SW2.1 (A)
Earth: C2.2, C3.2, D1.2 (A2), J1.3, J1.5, J2.1, J7.A1 (GND), J7.A12 (GND), J7.B1 (GND), J7.B12 (GND), J8.2, R2.2, R3.2, R4.2, SW1.3 (C), SW2.2 (B), U1.2 (GND), U1.3 (GND), U1.9 (GND), U2.3 (G), U2.8 (G)
unnamed: D2.1 (K), JP3.2 (B)
unnamed: C2.1, JP2.1 (A), JP3.1 (A), U1.1 (EN), U1.8 (VIN)
unnamed: C3.1, F1.1, JP4.1 (A), L1.2, R1.1, U1.5 (VOS)
unnamed: R1.2, R2.1, U1.4 (FB)
unnamed: L1.1, U1.7 (SW)
VBUS: D1.1 (A1), D2.2 (A), J7.A4 (VBUS), J7.A9 (VBUS), J7.B4 (VBUS), J7.B9 (VBUS)
VIN: J8.1, JP2.2 (B), JP4.2 (B)

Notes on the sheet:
LQM2HPN1R0MG0L


Board: 2 copper layers, 50.0 x 25.0 mm, 27 parts (0 on the bottom side), 15 nets.

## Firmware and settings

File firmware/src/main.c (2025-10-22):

#include <zephyr/kernel.h>
#include <zephyr/drivers/spi.h>
#include <zephyr/drivers/gpio.h>
#include <zephyr/dfu/mcuboot.h>
#include <zephyr/sys/poweroff.h>

#ifndef CONFIG_LPED_DEBUG_DISABLE_ACC
#include <libfxls89xx.h>
#endif

#include "lib/side/side.h"
#include "lib/bt/bt_dice.h"
#include "lib/phy/phy_dice.h"
#include "lib/dock/dock.h"
#include "lib/storage/storage.h"
#include "lib/side/side_defs.h"

#ifndef CONFIG_LPED_DEBUG_DISABLE_ACC
static const struct device *acc = DEVICE_DT_GET_ANY(nxp_fxls89xx);

// helper function to configure accelerometer into interrupt state
void acc_configure_int() {
	fxls89xx_configure_sdcd(acc, fxls89xx_sdcd_reference_update_always, fxls89xx_sdcd_input_mode_standard, -100, 100);
	fxls89xx_configure_sdcd_within(acc, false, true, true, true, 1, fxls89xx_sdcd_counter_decrement, fxls89xx_sdcd_logic_mode_and);

	fxls89xx_set_auto_timeout(acc, 2);
	fxls89xx_enable_auto_source(acc, fxls89xx_aslp_source_sdcd_wt, true);
	fxls89xx_enable_sdcd(acc, true);
	fxls89xx_interrupt_enable(acc, fxls89xx_interrupt_source_wake_out, true);
}

static struct gpio_callback acc_int1_callback_gpio;
//static struct gpio_callback int2_callback_gpio;
#endif

static struct gpio_callback int_dock_conn_callback_gpio;

static struct dock_dev dock;
static struct phy_dice_dev phy_dice;
static struct bt_dice_dev bt_dice;

#ifndef CONFIG_LPED_DEBUG_DISABLE_ACC
static uint8_t cap_state_interval_counter = 0;

// debounce timers for interrupts
static uint32_t acc_int1_debounce = 0;
static uint32_t acc_int2_debounce = 0;
#endif
static uint32_t dock_con_debounce = 0;

// worker threads invoked from ISRs
#ifndef CONFIG_LPED_DEBUG_DISABLE_ACC
struct k_work acc_int1_work;
struct k_work acc_int2_work;
#endif
struct k_work dock_btn_work;
struct k_work dock_con_work;
struct k_work dice_visible_timeout_work;
struct k_work dice_connectable_timeout_work;
struct k_work dice_connected_timeout_work;
struct k_work dice_connected_work;
struct k_work dice_disconnected_work;

static uint8_t ignore_dock_disconnect = false;

static uint32_t last_boot_time;

static uint8_t comm_mode;

#ifndef CONFIG_LPED_DEBUG_DISABLE_ACC
static side_definition_t side_def;
static dice_definition_t dice_def;
static uint8_t side_blink;
static uint8_t error_blink;
static uint8_t cap_state;

void acc_int1_callback(struct k_work *work) {
	storage_get_comm_mode(&comm_mode);

	if (fxls89xx_get_int_pin_state(acc, fxls89xx_interrupt_pin_int1)) {
		storage_get_current_dice_definition(&dice_def);

		determine_side(
			&dice_def,
			fxls89xx_get_acceleration(acc, fxls89xx_axis_x),
			fxls89xx_get_acceleration(acc, fxls89xx_axis_y),
			fxls89xx_get_acceleration(acc, fxls89xx_axis_z),
			&side_def
		);

		printk("Landed on number: %u\n", side_def.number);

		storage_get_side_blink(&side_blink);
		storage_get_error_blink(&error_blink);

		if (side_blink || error_blink) 	dice_led_off(&phy_dice);

		if (side_def.number != 0)   {
			if (side_blink) dice_led_start_animation(&phy_dice, &side_def.animation);

			if (comm_mode) 	dice_bt_set_dice_number(&bt_dice, &side_def.number, bt_message_dice_number);
			else 			dice_bt_broadcast(&side_def.number, bt_message_dice_number);
		}

		else {
			if (error_blink) dice_led_start_error_solid_animation(&phy_dice);

			if (comm_mode) 	dice_bt_set_dice_number(&bt_dice, NULL, bt_message_unknown);
			else 			dice_bt_broadcast(NULL, bt_message_unknown);
		}

		if (!IS_ENABLED(CONFIG_LPED_CAP_STATE_IN_ROLLING_MSG)) {
			dice_get_cap_state(&phy_dice, &cap_state);

#ifdef CONFIG_LPED_CAP_STATE_INTERVAL
			if (++cap_state_interval_counter >=x CONFIG_LPED_CAP_STATE_INTERVAL) {
				cap_state_interval_counter = 0;
				dice_get_cap_state(&phy_dice, &cap_state);

				if (comm_mode) 	dice_bt_set_cap_state(&bt_dice, &cap_state);
				else 			dice_bt_broadcast(&cap_state, bt_message_cap_state);
			}
#endif
		}
	}

	// Interrupt event started (movement started)
	else {
		if (IS_ENABLED(CONFIG_LPED_CAP_STATE_IN_ROLLING_MSG)) {
			dice_get_cap_state(&phy_dice, &cap_state);

			if (comm_mode) {
				dice_bt_set_cap_state(&bt_dice, &cap_state);
				dice_bt_set_dice_number(&bt_dice, NULL, bt_message_rolling);
			}

			else {
				dice_bt_broadcast(&cap_state, bt_message_rolling);
			}
		}

		else {
			cap_state_interval_counter = 0;
			if (comm_mode) 	dice_bt_set_dice_number(&bt_dice, NULL, bt_message_rolling);
			else 			dice_bt_broadcast(NULL, bt_message_rolling);
		}
	}
}

void acc_int2_callback(struct k_work *work) {
}
#endif

void dock_con_callback(struct k_work *work) {
	if (ignore_dock_disconnect) return;
	k_msleep(10);
	storage_get_comm_mode(&comm_mode);

	// Rising edge
	if (dock_get_conn_state()) {
		printk("Charging dock connected\n");
#ifndef CONFIG_LPED_DEBUG_DISABLE_ACC
		fxls89xx_set_mode(acc, fxls89xx_sys_mode_standby);
#endif

		if (bt_dice.status != bt_status_connected) dice_led_on_color(&phy_dice, &COLOR_BLUE_BRIGHT);
		dice_bt_set_connectable(&bt_dice);
	}

	// Falling edge
	else {
		printk("Charging dock disconnected\n");
		if (!comm_mode) {
			dice_bt_set_invisible(&bt_dice);
			dice_led_off(&phy_dice);
		}

		else {
			if (bt_dice.status != bt_status_connected) dice_led_on_color(&phy_dice, &COLOR_BLUE_BRIGHT);
			dice_bt_set_connectable(&bt_dice);
		}

#ifndef CONFIG_LPED_DEBUG_DISABLE_ACC
		acc_configure_int();
		fxls89xx_set_mode(acc, fxls89xx_sys_mode_active);
#endif
	}
}       

void bt_dice_get_acceleration_values_callback(int16_t *accel_values) {
#ifndef CONFIG_LPED_DEBUG_DISABLE_ACC
	fxls89xx_interrupt_enable(acc, fxls89xx_interrupt_source_wake_out, false);
    fxls89xx_set_int2_function(acc, fxls89xx_int2_function_trigger);
    fxls89xx_trigger_read(acc);
	while (!fxls89xx_data_ready(acc)) k_msleep(5);
    accel_values[0] = fxls89xx_get_acceleration(acc, fxls89xx_axis_x);
    accel_values[1] = fxls89xx_get_acceleration(acc, fxls89xx_axis_y);
    accel_values[2] = fxls89xx_get_acceleration(acc, fxls89xx_axis_z);
    fxls89xx_set_int2_function(acc, fxls89xx_int2_function_interrupt);
#endif
}

void bt_dice_get_cap_state_callback(uint8_t *cap_state) {
	dice_get_cap_state(&phy_dice, cap_state);
}

void bt_dice_set_ignore_dock_connection_callback(bool ignore) {
	ignore_dock_disconnect = ignore;
	if (!ignore_dock_disconnect) k_work_submit(&dock_con_work);
}

void bt_dice_set_animation_callback(const animation_t *animation) {
	dice_led_start_animation(&phy_dice, animation);
}

#ifndef CONFIG_LPED_DEBUG_DISABLE_ACC
void acc_int1_isr(const struct device *dev, struct gpio_callback *callback_gpio, uint32_t pins) {
	if (
		acc_int1_debounce + CONFIG_LPED_ACC_DEBOUNCE_TIME > k_uptime_get_32() || 
		last_boot_time + CONFIG_LPED_ACC_BOOT_DURATION > k_uptime_get_32()
	) {
		return;
	}
	k_work_submit(&acc_int1_work);
	acc_int1_debounce = k_uptime_get_32();
}

void acc_int2_isr(const struct device *dev, struct gpio_callback *callback_gpio, uint32_t pins) {
	if (
		acc_int2_debounce + CONFIG_LPED_ACC_DEBOUNCE_TIME > k_uptime_get_32() || 
		last_boot_time + CONFIG_LPED_ACC_BOOT_DURATION > k_uptime_get_32()
	) {
		return;
	}
	acc_int2_debounce = k_uptime_get_32();
}
#endif

void dock_con_isr(const struct device *dev, struct gpio_callback *callback_gpio, uint32_t pins) {
	if (dock_con_debounce + CONFIG_LPED_DOCK_DEBOUNCE_TIME > k_uptime_get_32()) return;
	k_work_submit(&dock_con_work);
	dock_con_debounce = k_uptime_get_32();
}

// Workers for handling bluetooth interaction - Pairing button long press, visibility timedout and connectable timedout
void dice_connectable_timeout_callback(struct k_work *work) 
{
	dice_bt_set_invisible(&bt_dice);
	dice_led_off(&phy_dice);
}

void dice_connected_timeout_callback(struct k_work *work) 
{
	ignore_dock_disconnect = false;
	dice_bt_set_invisible(&bt_dice);
	dice_led_off(&phy_dice);
}

void dice_connected_callback(struct k_work *work) 
{
	dice_led_start_connected_animation(&phy_dice);
}

void dice_disconnected_callback(struct k_work *work) 
{
	// Return this to default value in case that the client
	// application doesn't do it, which would require additional
	// restart of the die
	ignore_dock_disconnect = false;


	dice_bt_set_connectable(&bt_dice);
	dice_led_on_color(&phy_dice, &COLOR_BLUE_BRIGHT);
}

int main(void)
{
	storage_init();

	last_boot_time = k_uptime_get_32();

	if (IS_ENABLED(CONFIG_LPED_FACTORY_RESET_AT_STARTUP)) storage_clear();

	dice_bt_init(
		&bt_dice, 
		K_SECONDS(CONFIG_LPED_CONNECTABLE_TIMEOUT),
		K_SECONDS(CONFIG_LPED_CONNECTED_TIMEOUT),
		&dice_connectable_timeout_work,
		&dice_connected_timeout_work,  
		&dice_connected_work, 
		&dice_disconnected_work,
		bt_dice_get_acceleration_values_callback,
		bt_dice_get_cap_state_callback,
		bt_dice_set_ignore_dock_connection_callback,
		bt_dice_set_animation_callback
	);

	dice_phy_init(&phy_dice);

	dock_init(&dock);

#ifndef CONFIG_LPED_DEBUG_DISABLE_ACC
	k_work_init(&acc_int1_work, acc_int1_callback);
	k_work_init(&acc_int2_work, acc_int2_callback);
#endif
	k_work_init(&dock_con_work, dock_con_callback);
	k_work_init(&dice_connectable_timeout_work, dice_connectable_timeout_callback);
	k_work_init(&dice_connected_timeout_work, dice_connected_timeout_callback);
	k_work_init(&dice_connected_work, dice_connected_callback);
	k_work_init(&dice_disconnected_work, dice_disconnected_callback);

	dock_conn_int_init(&int_dock_conn_callback_gpio, dock_con_isr);

	// Accelerometer setup
#ifndef CONFIG_LPED_DEBUG_DISABLE_ACC
	fxls89xx_set_range(acc, fxls89xx_range_2g);
	fxls89xx_set_mode(acc, fxls89xx_sys_mode_standby);
	fxls89xx_configure_state(acc, fxls89xx_state_wake, fxls89xx_odr_3_125Hz, fxls89xx_power_mode_low);
	fxls89xx_configure_state(acc, fxls89xx_state_sleep, fxls89xx_odr_6_25Hz, fxls89xx_power_mode_low);
	acc_configure_int();
	fxls89xx_interrupt_bind(acc, fxls89xx_interrupt_source_wake_out, fxls89xx_interrupt_pin_int1, GPIO_INT_EDGE_BOTH, &acc_int1_callback_gpio, acc_int1_isr);
#endif

	dice_led_off(&phy_dice);

	k_msleep(CONFIG_LPED_ACC_BOOT_DURATION);

	if (IS_ENABLED(CONFIG_LPED_FORCE_CONNECTABLE_AT_STARTUP)) {
#ifndef CONFIG_LPED_DEBUG_DISABLE_ACC
		fxls89xx_set_mode(acc, fxls89xx_sys_mode_standby);
#endif
		dice_bt_set_connectable(&bt_dice);
		dice_led_on_color(&phy_dice, &COLOR_BLUE_BRIGHT);
	}

	else {
		if (IS_ENABLED(CONFIG_LPED_IGNORE_DOCK_AT_STARTUP)) {
#ifndef CONFIG_LPED_DEBUG_DISABLE_ACC
			fxls89xx_set_mode(acc, fxls89xx_sys_mode_active);
#endif
			storage_get_comm_mode(&comm_mode);
			if (comm_mode) {
				dice_bt_set_connectable(&bt_dice);
				dice_led_on_color(&phy_dice, &COLOR_BLUE_BRIGHT);
			}
		}

		else {
			k_work_submit(&dock_con_work);
		}
 	}

	printk("LPED running\n");

	// run debug animation if acc is disabled
#ifdef CONFIG_LPED_BOOT_ANIMATION
	k_msleep(CONFIG_LPED_ACC_BOOT_DURATION * 2); // Give space to all worker threads that could turn the LED back off prematurely
	dice_led_start_animation(&phy_dice, &animation_boot);
#endif

	return 0;
}

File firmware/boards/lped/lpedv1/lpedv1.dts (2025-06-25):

/dts-v1/;
#include <nordic/nrf52810_qfaa.dtsi>
#include "lpedv1-pinctrl.dtsi"

/ {
	model = "LPEDv1 board";
	compatible = "lped,lpedv1";

	chosen {
		zephyr,sram = &sram0;
		zephyr,flash = &flash0;
		zephyr,code-partition = &slot0_partition;
	};

	leds {
		compatible = "gpio-leds";
		diceled: dice_led {
			gpios = <&gpio0 6 (1 << 9)>;
			label = "Dice LED";
		};

		dockled: dock_led {
			gpios = <&gpio0 5 (1 << 9)>;
			label = "Dock LED";
		};
	};

	inputs: zephyr,user {
		dock_conn-gpios = <&gpio0 4 GPIO_PULL_DOWN>;
		io-channels = <&adc 0>;
	};

	buttons {
		compatible = "gpio-keys";
		dockbutton: dock_button {
			gpios = <&gpio0 9 GPIO_PULL_DOWN>;
			label = "dock_button";
		};
	};
};

&gpio0 {
	status = "okay";
};

&gpiote {
	status = "okay";
};

&spi0 {
	status = "okay";
	compatible = "nordic,nrf-spi";
	pinctrl-0 = <&spi0_default>;
	pinctrl-1 = <&spi0_sleep>;
	pinctrl-names = "default", "sleep";
	cs-gpios = <&gpio0 14 GPIO_ACTIVE_LOW>;
	fxls89xx: fxls89xx@0 {
		zephyr,pm-device-runtime-auto;
		compatible = "nxp,fxls89xx";
		reg = <0x0>;
		spi-max-frequency = <2000000>;
		int1-gpios = <&gpio0 12 GPIO_PULL_UP>;
		int2-gpios = <&gpio0 15 GPIO_PULL_UP>;
	};
};

&adc {
	status = "okay";
	#address-cells = <1>;
	#size-cells = <0>;
	channel@0 {
		reg = <0>;
		zephyr,gain = "ADC_GAIN_1_6";			// Gain of 1/6 with internal reference (0.6V) results in range of +-3.6V
		zephyr,reference = "ADC_REF_INTERNAL";
		zephyr,acquisition-time = <ADC_ACQ_TIME_DEFAULT>;
		zephyr,input-positive = <NRF_SAADC_AIN6>;
		zephyr,resolution = <12>;
	};
};


&flash0 {
	partitions {
		compatible = "fixed-partitions";
		#address-cells = <1>;
		#size-cells = <1>;

		boot_partition: partition@0 {
			label = "mcuboot";
			reg = <0x00000000 DT_SIZE_K(48)>;
		};

		slot0_partition: partition@c000 {
			label = "image-0";
			reg = <0x0000c000 DT_SIZE_K(56)>;
		};

		slot1_partition: partition@1a000 {
			label = "image-1";
			reg = <0x0001a000 DT_SIZE_K(56)>;
		};

		storage_partition: partition@28000 {
			label = "storage";
			reg = <0x00028000 DT_SIZE_K(32)>;
		};
	};
};

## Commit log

2025-06-25 chore: move to a new repo
    [2450AT42E010BE.step, APTD2012LSURCK.stp, FA-128_EPS.step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]
2025-07-20 chore: move lped pcb model to dir
    [lped_pcb.step]
2025-07-20 feat(hardware)!: v2 of LPED PCB
    * Changed MCU to nRF52833 (from nRF52810)
    * Added second LED
    * Used specialized filter instead of discrete components for ANT
    * Removed unnecessary pull-down resistor from miso
    * Removed DOCK_BTN
    [accelerometer.kicad_sch, lped.kicad_pcb, lped.kicad_sch]
2025-07-20 feat(firmware): added board definition for v2
2025-07-22 feat(hardware): replaced LEDs on dice
    * Replaced two red LEDs with single RGB LED (LTRB37G-4R4S)
    * Added more ground vias
    * Removed DOCK_LED
    [LTRBR37G-4R4S-0125-0.stp, lped.kicad_pcb, lped.kicad_sch]
2025-07-22 feat(hardware): remove unused parts from dock pcb
    * Removed LED from dock
    * Removed button from dock
    * Removed connection pins for LED and button
    [dice_conn.kicad_sch, lped_dock.kicad_pcb, lped_dock.kicad_sch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]
2025-07-23 feat(hardware): minor single dock improvements
    * Moved connection pins closer together
    * Added ground stiching
    [lped_dock.kicad_pcb]
2025-07-23 chore: restructure dock dir
    * Created separated dirs for modular and single dock
    [bay_insert.step, bottom_body.step, connector.kicad_sch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]
2025-08-18 feat(hardware): add battery charger and connector to single charger
    [battery.kicad_sch, dice_conn.kicad_sch, input.kicad_sch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]
2025-08-19 feat(hardware): added usb and manual input to programmer, added reset button and connection switch
    [lped_prog.kicad_pcb, lped_prog.kicad_sch]
2025-08-19 feat(hardware): added stiching to programmer
    [lped_prog.kicad_pcb]
2025-08-19 feat(hardware): chaged regulator
    [lped_prog.kicad_pcb, lped_prog.kicad_sch]
2025-08-19 fix(hardware): shrinked keep-out area under USB-C on programmer
    [lped_prog.kicad_pcb]
2025-08-19 feat(hardware): change regulator, add mounting hole to single charger
    [lped_dock.kicad_pcb, lped_dock.kicad_sch, regulator.kicad_sch]
2025-08-24 feat(hardware): improvements to dock battery system
    * Added current limiting resistor to battery
    * Added charging status LED
    * Changed side of battery connector
    [battery.kicad_sch, lped_dock.kicad_pcb, lped_dock.kicad_sch]
2025-08-24 fix(hardware): LPED PCB clean up
    [lped.kicad_pcb, lped.kicad_sch]
2025-09-09 chore(hardware): remove outdated BOM
    [complete_bom.csv]
2025-09-09 feat(hardware): add batt charger bypass solder jump
    [lped_dock.kicad_pcb, lped_dock.kicad_sch]
2025-09-21 fix(hardware): minor fixes before manufacturing
    Changed footprint of USB protection diode
    Changed footprint of Programmer fuse
    [battery.kicad_sch, lped.kicad_pcb, lped_dock.kicad_pcb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]
2025-10-10 feat(firmware): add new configs for LEDs
2025-10-10 feat(firmware): add RGB LED to the v2 device tree
2025-10-10 feat(firmware): new system for controlling Dice LEDs
    * Added new system for RGB LED control
    * It uses a separate thread for running the LED effects based on given animation structures
    * Animations can hold up to 20 animation steps with varying colors that can be selected from pallete of 16
    * Each color has its own duration
    * Each animation has its own fade type (none - changes instantly, fast and slow have preselected fade speeds, grad changes the colors for the whole duration between two colors)
    * Removed dock LED and Button function - they are not used anymore
    * Added predefined animation patterns for error and bluetooth
    [main.c]
2025-10-11 feat(firmware): added battery service
2025-10-11 feat(firmware): map cap soc on-board
    TODO: add more accurate mapping, such as LUT
2025-10-12 feat(firmware): added debug option to disable accelerometer
2025-10-12 chore(firmware): add dts for debug board
2025-10-13 feat(hardware): update dice 3d model for v2
    [die_6.FCStd]
2025-10-13 fix(firmware): fix behaviour when removed from dock
    [main.c]
2025-10-22 fix(firmware): fix led in lpedv2 device tree
2025-10-22 fix(firmware): use correct connected timeout, ignore EALREADY error from bt
    [main.c]
2025-10-22 feat(hardware): new 3D models for dice
    [die_6.FCStd, lped.kicad_pcb, lped_pcb.step]

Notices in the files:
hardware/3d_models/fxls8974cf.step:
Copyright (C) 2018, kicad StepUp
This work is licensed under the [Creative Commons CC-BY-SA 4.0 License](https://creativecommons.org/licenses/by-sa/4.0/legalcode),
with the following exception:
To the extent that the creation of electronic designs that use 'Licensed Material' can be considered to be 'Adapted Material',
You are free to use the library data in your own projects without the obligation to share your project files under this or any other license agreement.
